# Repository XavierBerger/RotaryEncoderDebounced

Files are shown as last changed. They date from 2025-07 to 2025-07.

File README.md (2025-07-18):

# Rotary Encoder Debounced

A rotary encoder tracks shaft rotation by outputting pulses. However, mechanical switches in encoders suffer from contact bounce, causing false signals.

This projet propose a solution to debounced Rotary Encoder signal at hardware level.

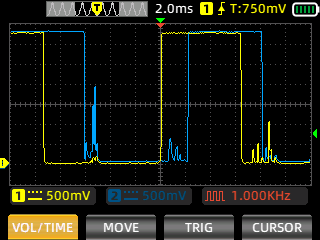
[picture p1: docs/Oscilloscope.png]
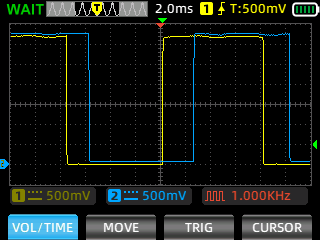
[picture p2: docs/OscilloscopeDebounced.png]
  

## The Problem

When encoder contacts close or open, they bounce, creating multiple rapid signal changes. These can be misinterpreted as several rotations or direction changes.

  
*Signal captured on a rotary encoder without debouncer*

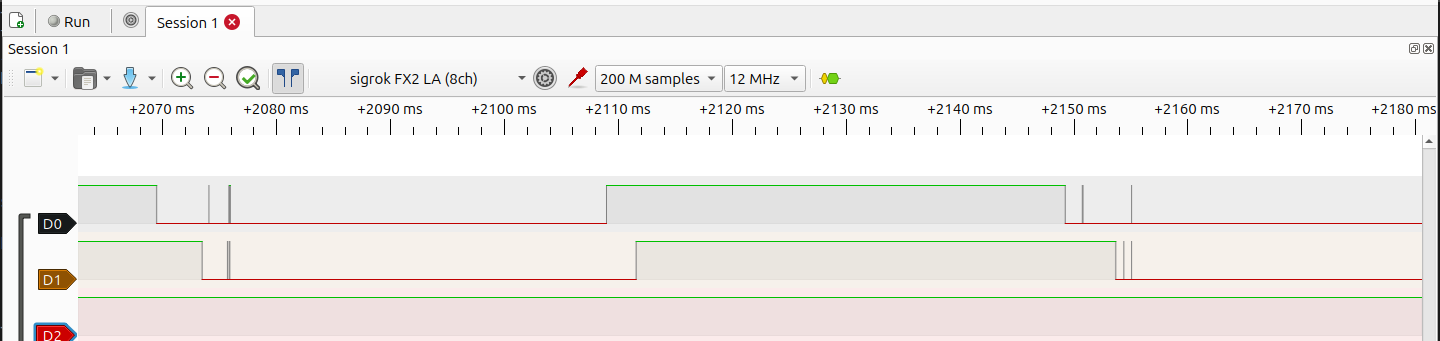
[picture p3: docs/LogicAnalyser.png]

*Resulting signal of a noisy input*

## The solutions

### Software Debouncing is not statisfying

Software debouncing filters out noise but has drawbacks:

* Timing needs are precise and hard to maintain at varying speeds.

* Processing overhead increases, burdening limited systems.

* Complexity rises with advanced algorithms.

### Hardware Debouncing is more reliable

This project uses hardware to debounce signals reliably by associating low-pass filters with schmitt triggers.

#### Low-Pass Filter

A simple RC circuit smooths the signal by filtering high-frequency noise, averaging rapid changes.

Filter has been designed to have a cutoff frequency of 1,59kHz with a time constant of 100µs.

#### Schmitt Trigger

Schmitt trigger, with two voltage thresholds, converts the filtered signal to a clean digital output. Hysteresis prevents noise from causing false transitions.

This combination removes bounce issues and provide a clean signal where noise is removed.

Hardware has been designed to use the smallest possible PCB. Pin header have been placed to ensure connectivity as well as mounting solution. Pin header placement have been placed to be compatible with breadboards.

## Realisation
Schematic, PCB, 3D views are designed with KiCad 9 with the following plugins:

* Interactive Html Bom [🔗](https://github.com/openscopeproject/InteractiveHtmlBom)  
  See the bill of material [here](https://xavierberger.github.io/RotaryEncoderDebounced/ibom.html)
* KiCAD JLCPCB tools [🔗](https://github.com/bouni/kicad-jlcpcb-tools)  
  This plugin allows you to search the JLCPCB parts database, assign LCSC article numbers to your parts, generate production files for JLCPCB and much more.
* Fabrication Toolkit [🔗](https://github.com/bennymeg/Fabrication-Toolkit)  
  Toolkit for automating PCB fabrication process with KiCad and JLCPCB. 

*Note: I used* **Fabrication Toolkit** *to generate production file since I noticed that component orientation of component is correct while it wans't in* **KiCAD JLCPCB tools**.

Components have been choosen to be "**Basic**" parts of JLCPCB to reduce the manufactirung cost.



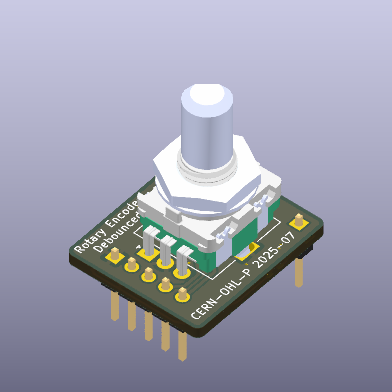
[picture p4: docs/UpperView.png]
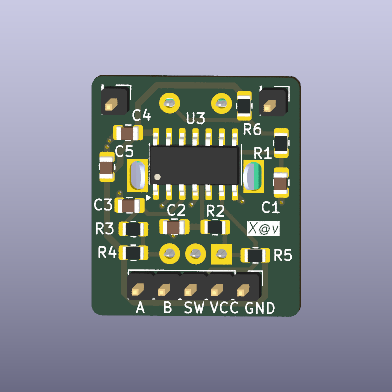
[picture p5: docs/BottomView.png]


The cost of the PCB fabrication and SMD assembly (so without the rotary encoder and pin headers) is about 7€ for 5 pieces.

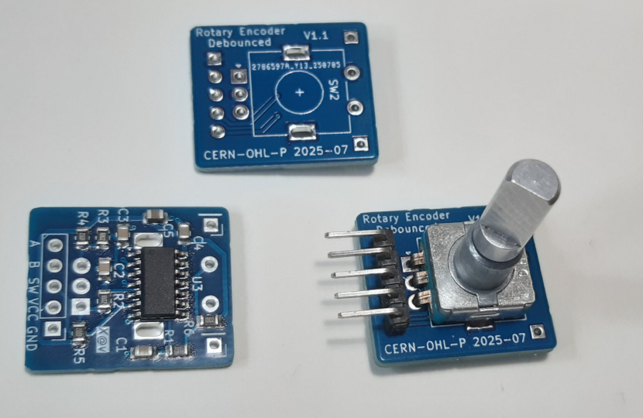
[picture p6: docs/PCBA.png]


## Analysis of results

On the oscilloscope, we can see a clean signal. The noise has been filtered-out.

  
*Signal captured on a rotary encoder with hardware debouncer*

The resulting signal captured with a logical analyser is also clean.

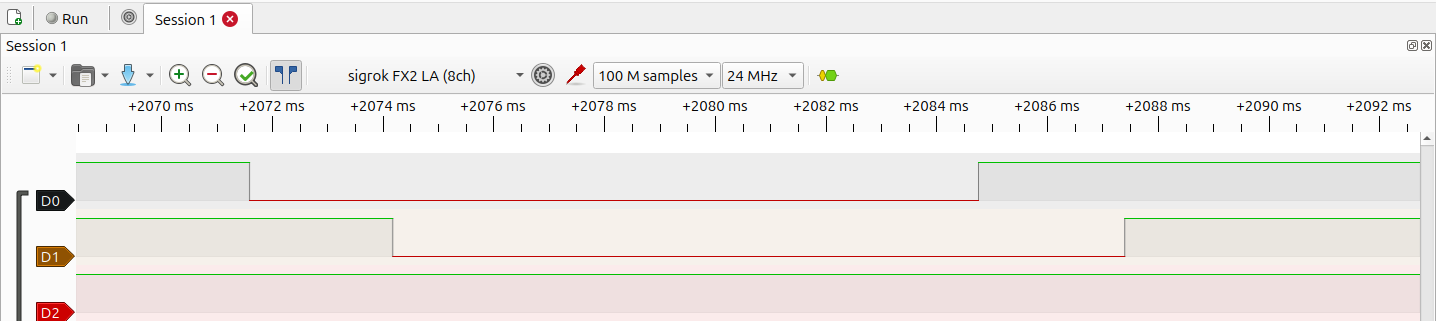
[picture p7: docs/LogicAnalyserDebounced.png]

*The resulting signal is clean*

Even when the capture rate is pushed up to the limit of the logical analyser, the signal remain clean.

Software debouncer is then no more needed and it is possible to base the algorithm on edge detection.

## License

Licensed under [CERN-OHL-P](LICENCE.txt). Free to use and modify.

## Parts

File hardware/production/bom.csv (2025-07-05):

Designator | Footprint | Quantity | Value | LCSC Part #
C1, C2, C3 | 0805 | 3 | 10n | C1710
C4 | 0805 | 1 | 100n | C49678
C5 | 0805 | 1 | 1u | C28323
R1, R2, R3, R4, R5, R6 | 0805 | 6 | 10k | C17414
U3 | SOIC-14_3.9x8.7mm_P1.27mm | 1 | 74HC14 | C5605

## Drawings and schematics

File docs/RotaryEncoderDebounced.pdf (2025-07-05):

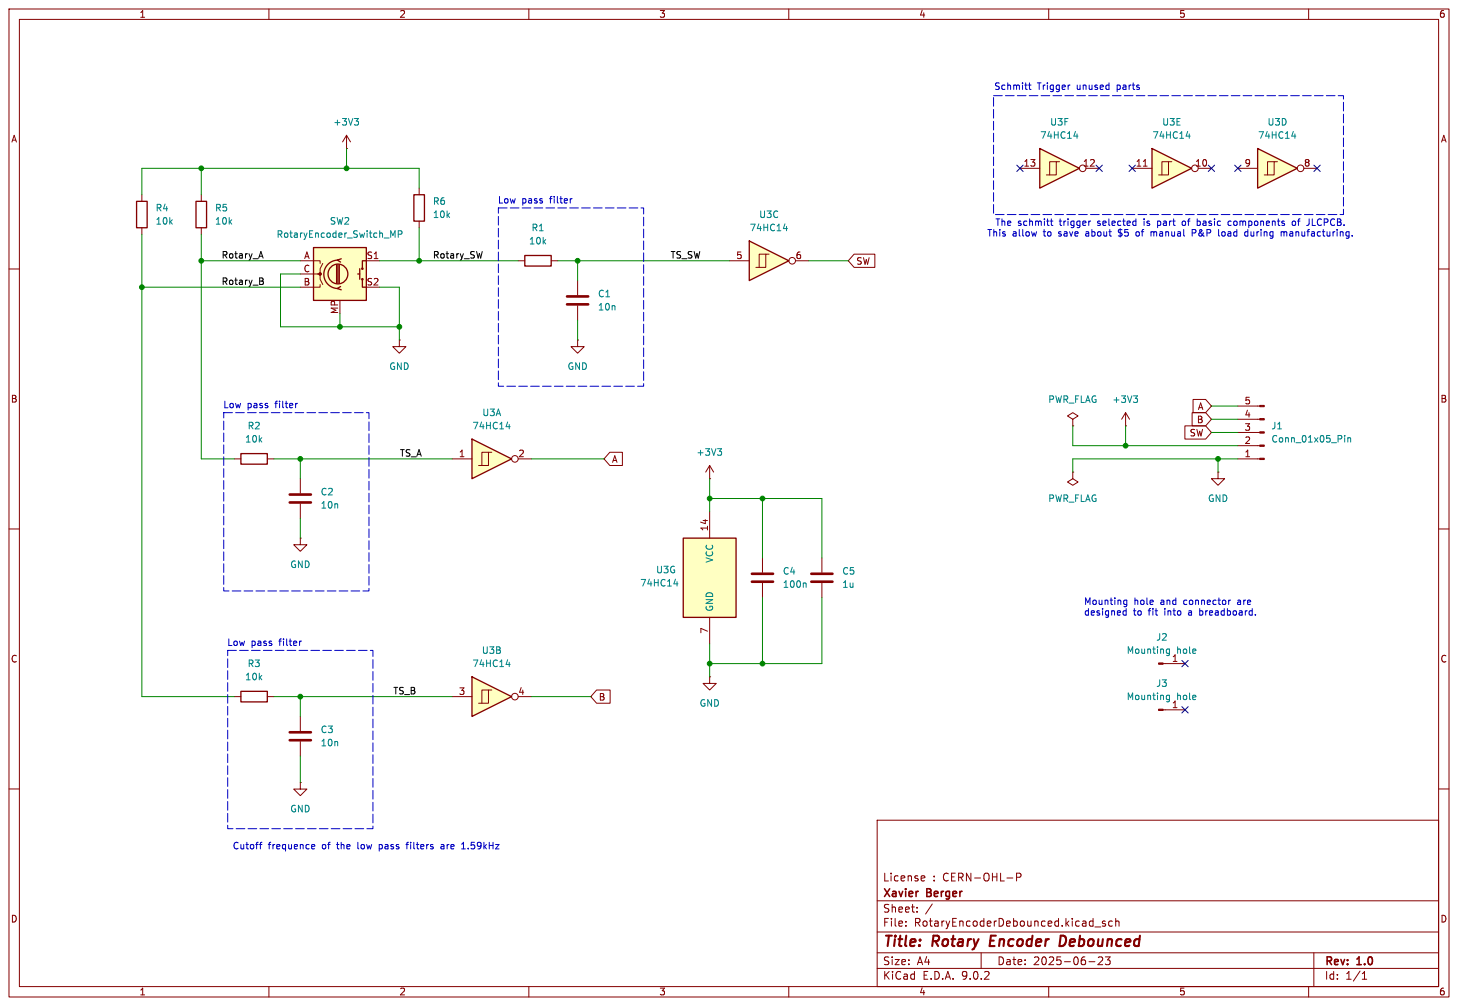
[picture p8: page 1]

Id: 1/1 Title: Rotary Encoder Debounced

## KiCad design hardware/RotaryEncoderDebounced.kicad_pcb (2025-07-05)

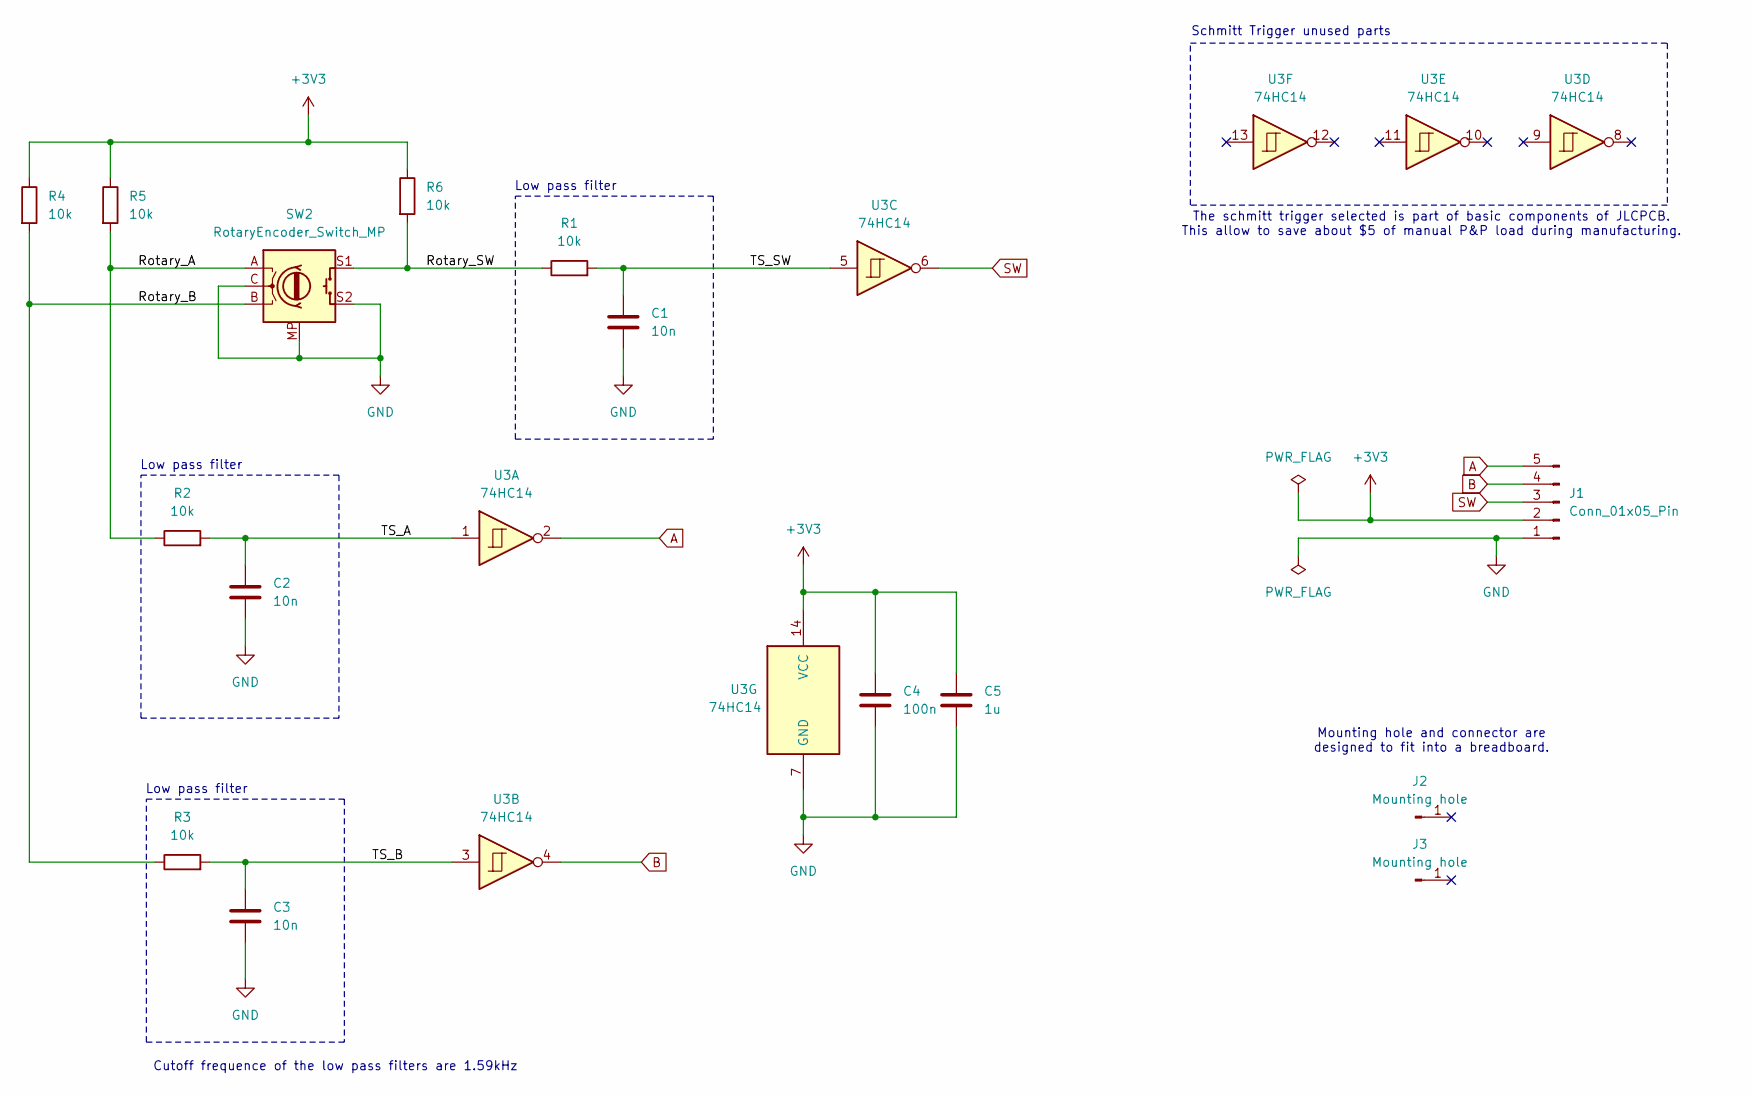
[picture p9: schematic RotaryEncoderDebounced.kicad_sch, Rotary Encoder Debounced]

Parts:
C1, C2, C3: 10n; C_0805_2012Metric
C4: 100n; C_0805_2012Metric
C5: 1u; C_0805_2012Metric
J1: Conn_01x05_Pin; PinHeader_1x05_P2.54mm_Vertical
J2, J3: Mounting hole; PinHeader_1x01_P2.54mm_Vertical
R1, R2, R3, R4, R5, R6: 10k; R_0805_2012Metric
SW2: RotaryEncoder_Switch_MP; RotaryEncoder_Alps_EC11E-Switch_Vertical_H20mm
U3: 74HC14; SOIC-14_3.9x8.7mm_P1.27mm

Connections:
+3V3: C4.1, C5.1, J1.2, R4.1, R5.1, R6.1, U3.14 (VCC)
/Rotary_A: R2.1, R5.2, SW2.A
/Rotary_B: R3.1, R4.2, SW2.B
/Rotary_SW: R1.1, R6.2, SW2.S1
/TS_A: C2.1, R2.2, U3.1
/TS_B: C3.1, R3.2, U3.3
/TS_SW: C1.1, R1.2, U3.5
A: J1.5, U3.2
B: J1.4, U3.4
GND: C1.2, C2.2, C3.2, C4.2, C5.2, J1.1, SW2.C, SW2.MP, SW2.S2, U3.7 (GND)
SW: J1.3, U3.6

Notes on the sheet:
Mounting hole and connector are designed to fit into a breadboard.
Low pass filter
Schmitt Trigger unused parts
Cutoff frequence of the low pass filters are 1.59kHz
The schmitt trigger selected is part of basic components of JLCPCB. This allow to save about $5 of manual P&P load during manufacturing.

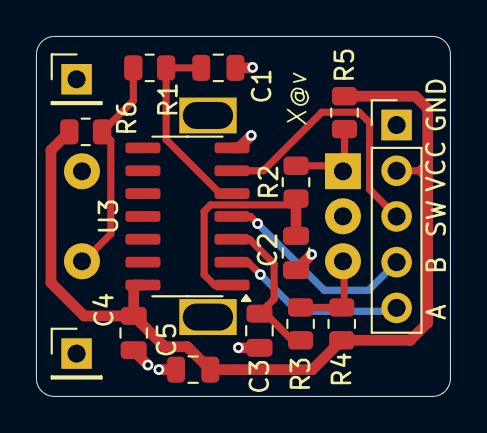
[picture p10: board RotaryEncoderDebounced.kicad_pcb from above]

Board: 2 copper layers, 23.0 x 20.0 mm, 16 parts (1 on the bottom side), 11 nets.

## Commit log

2025-07-05 feat(hardware): Add KiCad design
    [RotaryEncoderDebounced.kicad_pcb, RotaryEncoderDebounced.kicad_sch, bom.csv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]
2025-07-05 doc: Add datasheet of Schmitt Trigger and Rotary encoder
2025-07-05 doc: Update README to point to interactive bom in gh-pages
2025-07-18 doc: Add photo of PCB assembled

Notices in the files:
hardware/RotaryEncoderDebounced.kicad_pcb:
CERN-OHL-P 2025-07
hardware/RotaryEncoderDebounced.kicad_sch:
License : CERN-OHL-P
